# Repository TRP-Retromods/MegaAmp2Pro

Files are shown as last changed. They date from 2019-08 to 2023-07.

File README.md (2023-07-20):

# Mega Amp 2.0 Pro
Original design by Ace and Villahed94

What makes the Mega Amp 2.0 different from the original design?
Due to limitations of the chosen op-amps on the original Mega Amp, volume levels are limited to those of every Genesis made from the VA0 Genesis Model 2 onwards. With new components chosen for the Mega Amp 2.0, you can now blow your ears out with sound even louder than the loudest Genesis Model 1s.
Every Genesis will now be able to drive headphones, as well. The transistor buffers from the original design are gone, replaced by a TDA1308, a dual op-amp with a built-in headphone driver. It is this chip that is able to bring the higher volume and also simplify the design by integrating a superior headphone driver.
The Mega Amp 2.0 retains the 3.68KHz low-pass filtering for Genesis Model 1-like audio on the filtered setup, but the unfiltered setup now goes beyond the audible spectrum, filtering frequencies past 24.56KHz for the clearest sound possible.

This is the big one, the full-featured Mega Amp 2.0. It has it all: multiple different filter setups, Stereo and Mono audio, AND the added bonus of Sega CD audio mixing (Sega CD Model 2 or modded Sega CD Model 1 required to take advantage of this). Anyone who owns a Sega CD can choose what kind of audio they want out of their Genesis and Sega CD.

To sum up the Mega Amp 2.0:
-An even simpler design over the original Mega Amp (excluding the Mega Amp 2.0 Pro)
-Filtered circuits deliver the same sound as a VA0 to VA2 Genesis Model 1 minus distortion
-Unfiltered circuits deliver the full spectrum of the Genesis' audio output
-The loudest audio levels of any audio amp for the Genesis, including Sega’s amp for the VA3 Genesis Model 1
-Improved headphone support
-Sega CD pass-through for the Mega Amp 2.0 Pro for a true replacement audio circuit with no loss in functionality
-Mega Amp 2.0 Pro can add Sega CD pass-through to the Genesis Model 1

Sega-16 forums are downs, so I compile all explanation and installation in this doc: https://github.com/TRP-Retromods/MegaAmp2Pro/blob/master/MEGAAMP_2_DOC+INSTALL_V1.pdf

Quick Guide to help soldering the components on the PCB: https://github.com/TRP-Retromods/MegaAmp2Pro/blob/master/MEGAMP_2_PRO_QUICK_GUIDE_V3.pdf

Boards can be ordered on OSHPark https://oshpark.com/shared_projects/v1SMwG5q

https://youtu.be/V17gc4aD0Z8

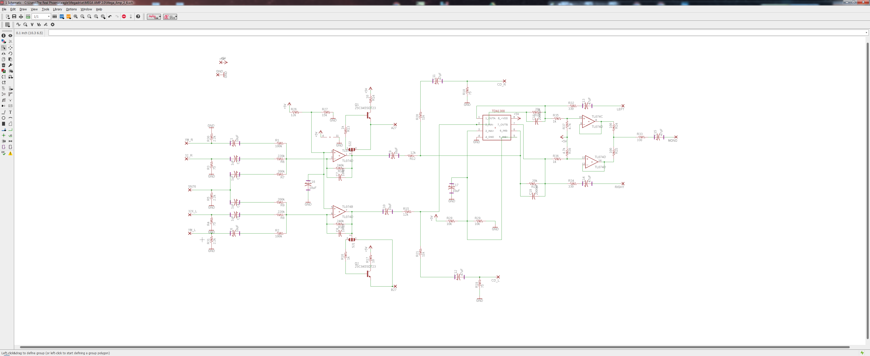
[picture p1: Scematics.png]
schematic


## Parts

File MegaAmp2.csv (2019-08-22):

Manufacturer Part Number | Manufacturer | Digi-Key Part Number | Customer Reference | Reference Designator | Packaging | Part Status | Quantity | Unit Price | Extended Price | Quantity Available | Mfg Std Lead Time | Description | RoHS Status | Lead Free Status | REACH Status | US Tariff Status
865080340001 | Wurth Electronics Inc. | 732-8411-1-ND | Sega Mega Amp 2.0 PRO | C1, C6, C9, C10, C16, C17 | Cut Tape (CT) | Active | 6 | 0.25000 | $1.50 | 3639 | 24 Weeks | CAP 10 UF 20% 16 V | RoHS Compliant | Lead free | REACH Unaffected | Tariff Eligible
865080640001 | Wurth Electronics Inc. | 732-8446-1-ND | Sega Mega Amp 2.0 PRO | C2, C3, C4, C5 | Cut Tape (CT) | Active | 4 | 0.26000 | $1.04 | 1479 | 24 Weeks | CAP 1 UF 20% 50 V | RoHS Compliant | Lead free | REACH Unaffected | Tariff Eligible
865080342006 | Wurth Electronics Inc. | 732-8416-1-ND | Sega Mega Amp 2.0 PRO | C11, C12, C13, C14, C15 | Cut Tape (CT) | Active | 5 | 0.28000 | $1.40 | 3305 | 24 Weeks | CAP 47 UF 20% 16 V | RoHS Compliant | Lead free | REACH Unaffected | Tariff Eligible
CL10C181JB8NNNC | Samsung Electro-Mechanics | 1276-1255-1-ND | Sega Mega Amp 2.0 PRO | C7, C8 (Mix Filtered) | Cut Tape (CT) | Active | 2 | 0.15000 | $0.30 | 439175 | Not Available | CAP CER 180PF 50V C0G/NP0 0603 | RoHS Compliant | Lead free | REACH Unaffected
CL10B202KB8NNNC | Samsung Electro-Mechanics | 1276-1983-1-ND | Sega Mega Amp 2.0 PRO | C18, C20 (Full Filtered) | Cut Tape (CT) | Active | 2 | 0.15000 | $0.30 | 260929 | Not Available | CAP CER 2000PF 50V X7R 0603 | RoHS Compliant | Lead free | REACH Unaffected | Tariff Eligible
TMBT3904,LM | Toshiba Semiconductor and Storage | TMBT3904LMCT-ND | Sega Mega Amp 2.0 PRO | Q1, Q2 | Cut Tape (CT) | Active | 2 | 0.28000 | $0.56 | 1255 | 12 Weeks | TRANS NPN 50V 0.15A SOT23-3 | RoHS Compliant | Lead free | Not Available
TL074CD | Texas Instruments | 296-1283-5-ND | Sega Mega Amp 2.0 PRO | TL074 | Tube | Active | 1 | 0.91000 | $0.91 | 2910 | 6 Weeks | IC INST AMP 4 CIRCUIT 14SOIC | RoHS Compliant | Lead free | REACH Unaffected
RMCF0603FT10R0 | Stackpole Electronics Inc | RMCF0603FT10R0CT-ND | Sega Mega Amp 2.0 PRO | R14, R17 | Cut Tape (CT) | Active | 2 | 0.15000 | $0.30 | 419828 | 17 Weeks | RES 10 OHM 1% 1/10W 0603 | RoHS Compliant | Lead free | REACH Unaffected | Tariff Eligible
RC0603FR-07100RL | Yageo | 311-100HRCT-ND | Sega Mega Amp 2.0 PRO | R24, R25 | Cut Tape (CT) | Active | 2 | 0.15000 | $0.30 | 26290992 | 16 Weeks | RES SMD 100 OHM 1% 1/10W 0603 | RoHS Compliant | Lead free | REACH Unaffected | Tariff Eligible
RMCF0603FT75R0 | Stackpole Electronics Inc | RMCF0603FT75R0CT-ND | Sega Mega Amp 2.0 PRO | R3, R4, R18, R19 | Cut Tape (CT) | Active | 4 | 0.15000 | $0.60 | 150899 | 17 Weeks | RES 75 OHM 1% 1/10W 0603 | RoHS Compliant | Lead free | REACH Unaffected | Tariff Eligible
CRGH0603F2K2 | TE Connectivity Passive Product | A129540CT-ND | Sega Mega Amp 2.0 PRO | R5, R30, R31 | Cut Tape (CT) | Active | 3 | 0.15000 | $0.45 | 16703 | 28 Weeks | CRGH0603 1% 2K2 0.2W | RoHS Compliant | Lead free | Not Available
RMCF0603FT11K0 | Stackpole Electronics Inc | RMCF0603FT11K0CT-ND | Sega Mega Amp 2.0 PRO | R20, R21 | Cut Tape (CT) | Active | 2 | 0.15000 | $0.30 | 140617 | 17 Weeks | RES 11K OHM 1% 1/10W 0603 | RoHS Compliant | Lead free | REACH Unaffected | Tariff Eligible
RMCF0603FT12K0 | Stackpole Electronics Inc | RMCF0603FT12K0CT-ND | Sega Mega Amp 2.0 PRO | R12, R15, R26 | Cut Tape (CT) | Active | 3 | 0.15000 | $0.45 | 333582 | 17 Weeks | RES 12K OHM 1% 1/10W 0603 | RoHS Compliant | Lead free | REACH Unaffected | Tariff Eligible
RMCF0603FG1K00 | Stackpole Electronics Inc | RMCF0603FG1K00CT-ND | Sega Mega Amp 2.0 PRO | R13, R16, R35, R36 | Cut Tape (CT) | Active | 2 | 0.15000 | $0.30 | 182303 | 17 Weeks | RES 1K OHM 1% 1/10W 0603 | RoHS Compliant | Lead free | REACH Unaffected | Tariff Eligible
RMCF0603FT16K0 | Stackpole Electronics Inc | RMCF0603FT16K0CT-ND | Sega Mega Amp 2.0 PRO | R27 | Cut Tape (CT) | Active | 1 | 0.15000 | $0.15 | 43103 | 17 Weeks | RES 16K OHM 1% 1/10W 0603 | RoHS Compliant | Lead free | REACH Unaffected | Tariff Eligible
RMCF0603FT15K0 | Stackpole Electronics Inc | RMCF0603FT15K0CT-ND | Sega Mega Amp 2.0 PRO | R27 | Cut Tape (CT) | Active | 1 | 0.15000 | $0.15 | 245293 | 17 Weeks | RES 15K OHM 1% 1/10W 0603 | RoHS Compliant | Lead free | REACH Unaffected | Tariff Eligible
RC0603FR-0720KL | Yageo | 311-20.0KHRCT-ND | Sega Mega Amp 2.0 PRO | R22, R23 | Cut Tape (CT) | Active | 2 | 0.15000 | $0.30 | 8330634 | 16 Weeks | RES SMD 20K OHM 1% 1/10W 0603 | RoHS Compliant | Lead free | REACH Unaffected | Tariff Eligible
RMCF0603FT200K | Stackpole Electronics Inc | RMCF0603FT200KCT-ND | Sega Mega Amp 2.0 PRO | R7, R9 | Cut Tape (CT) | Active | 2 | 0.15000 | $0.30 | 1424 | 17 Weeks | RES 200K OHM 1% 1/10W 0603 | RoHS Compliant | Lead free | REACH Unaffected
RMCF0603FG100K | Stackpole Electronics Inc | RMCF0603FG100KCT-ND | Sega Mega Amp 2.0 PRO | R1, R2 | Cut Tape (CT) | Active | 2 | 0.15000 | $0.30 | 305802 | 17 Weeks | RES 100K OHM 1% 1/10W 0603 | RoHS Compliant | Lead free | REACH Unaffected | Tariff Eligible
RMCF0603FT240K | Stackpole Electronics Inc | RMCF0603FT240KCT-ND | Sega Mega Amp 2.0 PRO | R11, R10 | Cut Tape (CT) | Active | 2 | 0.15000 | $0.30 | 4599 | 17 Weeks | RES 240K OHM 1% 1/10W 0603 | RoHS Compliant | Lead free | REACH Unaffected
C0603C270J5GACTU | KEMET | 399-1054-1-ND | Sega Mega Amp 2.0 PRO | C7, C8 (Unfiltered) | Cut Tape (CT) | Active | 2 | 0.15000 | $0.30 | 316020 | 33 Weeks | CAP CER 27PF 50V C0G/NP0 0603 | RoHS Compliant | Lead free | REACH Unaffected
CR0603-FX-1002ELF | Bourns Inc. | CR0603-FX-1002ELFCT-ND | Sega Mega Amp 2.0 PRO | R28, R29 | Cut Tape (CT) | Active | 2 | 0.15000 | $0.30 | 239308 | 14 Weeks | RES SMD 10K OHM 1% 1/10W 0603 | RoHS Compliant | Lead free | REACH Unaffected
KTR03EZPF2203 | Rohm Semiconductor | RHM220KAYCT-ND | Sega Mega Amp 2.0 PRO | R6, R8 | Cut Tape (CT) | Active | 2 | 0.23000 | $0.46 | 1571 | 10 Weeks | RES SMD 220K OHM 1% 1/10W 0603 | RoHS Compliant | Lead free | REACH Unaffected
RMCF0603FT330R | Stackpole Electronics Inc | RMCF0603FT330RCT-ND | Sega Mega Amp 2.0 PRO | R32, R33, R34 | Cut Tape (CT) | Active | 3 | 0.15000 | $0.45 | 379642 | 17 Weeks | RES 330 OHM 1% 1/10W 0603 | RoHS Compliant | Lead free | REACH Unaffected
SA5532ADR | Texas Instruments | 296-16994-1-ND | Sega Mega Amp 2.0 PRO | TDA1308 replacement | Cut Tape (CT) | Active | 1 | 1.31000 | $1.31 | 15908 | 6 Weeks | IC INST AMP 2 CIRCUIT 8SOIC | RoHS Compliant | Lead free | REACH Unaffected
RMCF0603FT4K70 | Stackpole Electronics Inc | RMCF0603FT4K70CT-ND | Sega Mega Amp 2.0 PRO | R37, R38 | Cut Tape (CT) | Active | 2 | 0.15000 | $0.30 | 718263 | 17 Weeks | RES 4.7K OHM 1% 1/10W 0603 | RoHS Compliant | Lead free | REACH Unaffected | Tariff Eligible

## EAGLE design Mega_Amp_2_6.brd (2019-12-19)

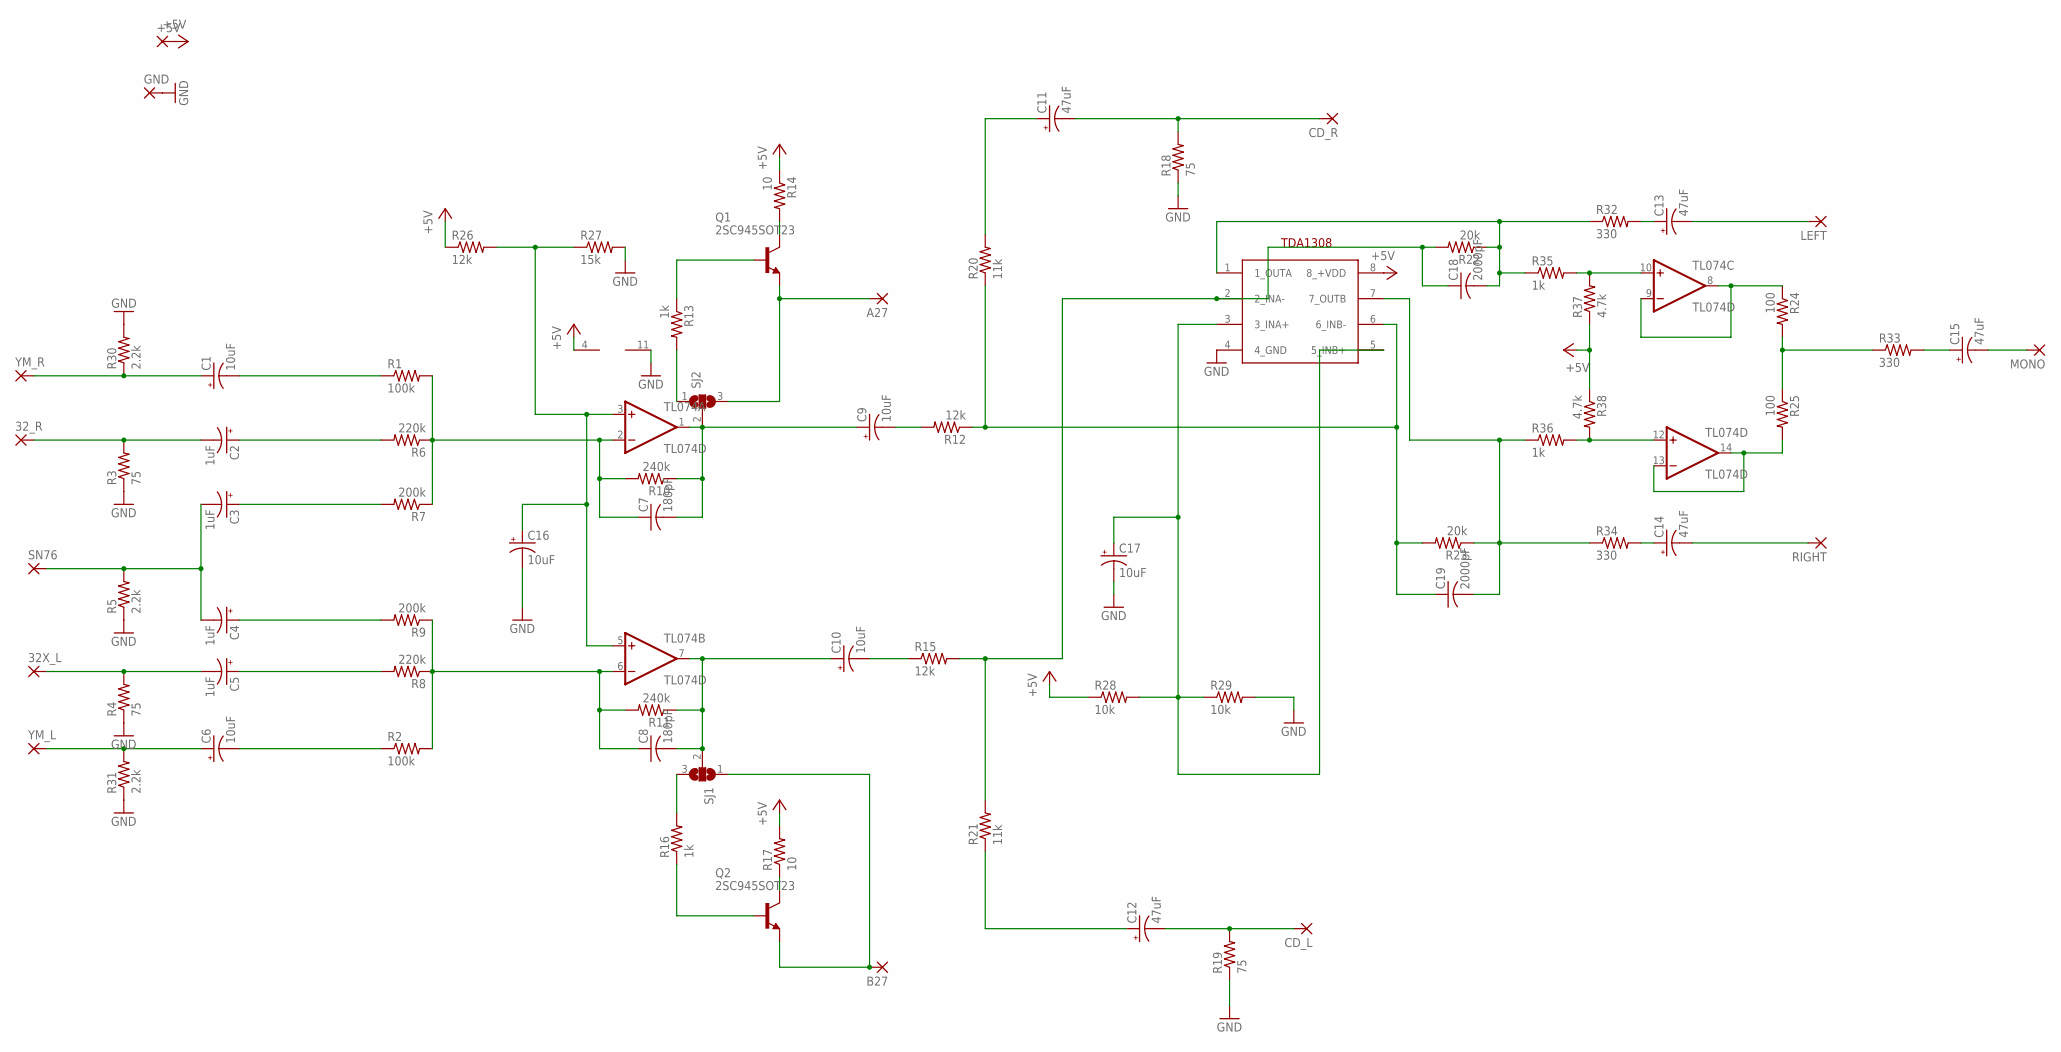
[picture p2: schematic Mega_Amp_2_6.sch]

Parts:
32X_L, 32_R: SMD2; SMD1,27-2,54
+5V: SMD5; SMD2,54-5,08
A27: SMD2; SMD1,27-2,54
B27: SMD2; SMD1,27-2,54
C1, C6, C9, C10, C16, C17: 10uF; 153CLV-0405
C2, C3, C4, C5: 1uF; 153CLV-0405
C7, C8: 180pF; C0603
C11, C12, C13, C14, C15: 47uF; 153CLV-0505
C18, C19: 2000pF; C0603
CD_L: SMD2; SMD1,27-2,54
CD_R: SMD2; SMD1,27-2,54
GND: SMD5; SMD2,54-5,08
LEFT: SMD2; SMD1,27-2,54
MONO: SMD2; SMD1,27-2,54
Q1, Q2: 2SC945SOT23; SOT23
R1, R2: 100k; R0603
R3, R4, R18, R19: 75; R0603
R5, R30, R31: 2.2k; R0603
R6, R8: 220k; R0603
R7, R9: 200k; R0603
R10, R11: 240k; R0603
R12, R15, R26: 12k; R0603
R13, R16, R35, R36: 1k; R0603
R14, R17: 10; R0603
R20, R21: 11k; R0603
R22, R23: 20k; R0603
R24, R25: 100; R0603
R27: 15k; R0603
R28, R29: 10k; R0603
R32, R33, R34: 330; R0603
R37, R38: 4.7k; R0603
RIGHT: SMD2; SMD1,27-2,54
SJ1, SJ2: SJ2W; SJ_2
SN76: SMD2; SMD1,27-2,54
TDA1308: TDA1308SO8; SO8
TL074: TL074D; SO14
YM_L: SMD2; SMD1,27-2,54
YM_R: SMD2; SMD1,27-2,54

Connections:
+5V: +5V.1, R14.1, R17.2, R26.1, R28.1, R37.1, R38.1, TDA1308.8 (8_+VDD), TL074.4 (V+)
GND: C16.-, C17.-, GND.1, R3.1, R4.1, R5.1, R18.1, R19.1, R27.2, R29.2, R30.2, R31.1, TDA1308.4 (4_GND), TL074.11 (V-)
unnamed: C1.+, R30.1, YM_R.1
unnamed: C1.-, R1.1
unnamed: 32_R.1, C2.-, R3.2
unnamed: C2.+, R6.2
unnamed: C3.-, C4.-, R5.2, SN76.1
unnamed: C3.+, R7.2
unnamed: C4.+, R9.2
unnamed: C7.1, R1.2, R6.1, R7.1, R10.2, TL074.2 (-IN)
unnamed: C8.1, R2.2, R8.1, R9.1, R11.2, TL074.6 (-IN)
unnamed: C5.+, R8.2
unnamed: C6.-, R2.1
unnamed: 32X_L.1, C5.-, R4.2
unnamed: C6.+, R31.2, YM_L.1
unnamed: C16.+, R26.2, R27.1, TL074.3 (+IN), TL074.5 (+IN)
unnamed: C7.2, C9.+, R10.1, SJ2.2, TL074.1 (OUT)
unnamed: Q1.1 (B), R13.1
unnamed: C8.2, C10.+, R11.1, SJ1.2, TL074.7 (OUT)
unnamed: Q1.3 (C), R14.2
unnamed: A27.1, Q1.2 (E), SJ2.3
unnamed: C9.-, R12.2
unnamed: C19.1, R12.1, R20.1, R23.2, TDA1308.6 (6_INB-)
unnamed: C11.+, R20.2
unnamed: C11.-, CD_R.1, R18.2
unnamed: C13.-, LEFT.1
unnamed: C15.-, MONO.1
unnamed: R24.2, R25.1, R33.1
unnamed: C10.-, R15.1
unnamed: C17.+, R28.2, R29.1, TDA1308.3 (3_INA+), TDA1308.5 (5_INB+)
unnamed: Q2.1 (B), R16.1
unnamed: Q2.3 (C), R17.1
unnamed: B27.1, Q2.2 (E), SJ1.1
unnamed: C12.+, R21.1
unnamed: C12.-, CD_L.1, R19.2
unnamed: C18.1, R15.2, R21.2, R22.2, TDA1308.2 (2_INA-)
unnamed: R24.1, TL074.8 (OUT), TL074.9 (-IN)
unnamed: R25.2, TL074.13 (-IN), TL074.14 (OUT)
unnamed: C14.-, RIGHT.1
unnamed: C13.+, R32.2
unnamed: C14.+, R34.2
unnamed: C15.+, R33.2
unnamed: R13.2, SJ2.1
unnamed: C19.2, R23.1, R34.1, R36.1, TDA1308.7 (7_OUTB)
unnamed: R16.2, SJ1.3
unnamed: R35.2, R37.2, TL074.10 (+IN)
unnamed: C18.2, R22.1, R32.1, R35.1, TDA1308.1 (1_OUTA)
unnamed: R36.2, R38.2, TL074.12 (+IN)

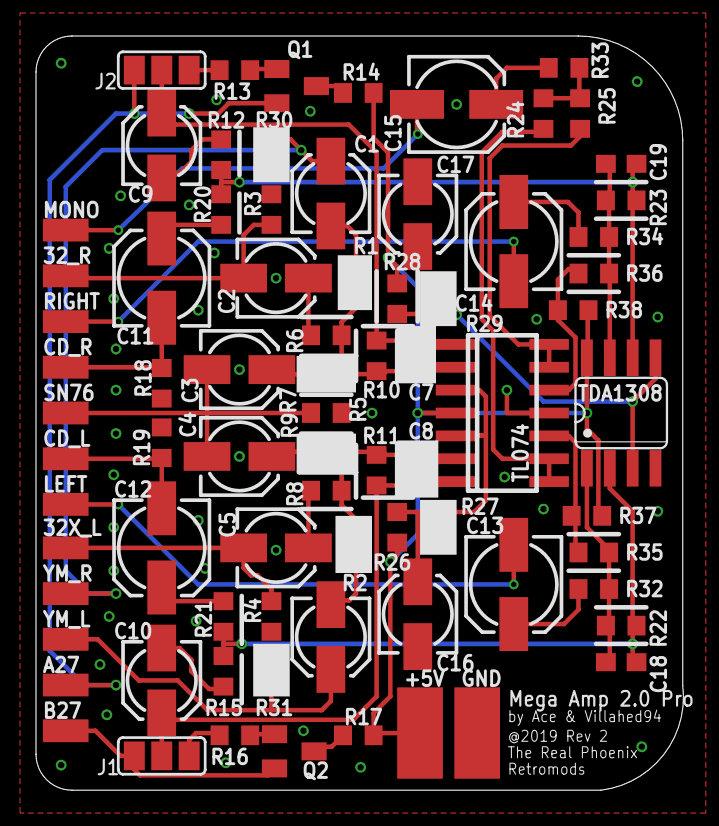
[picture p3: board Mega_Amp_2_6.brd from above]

Board: 2 copper layers, 36.0 x 41.9 mm, 77 parts (0 on the bottom side), 48 nets.

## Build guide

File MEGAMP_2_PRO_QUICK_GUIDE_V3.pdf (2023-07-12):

# MEGA AMP 2.0 PRO

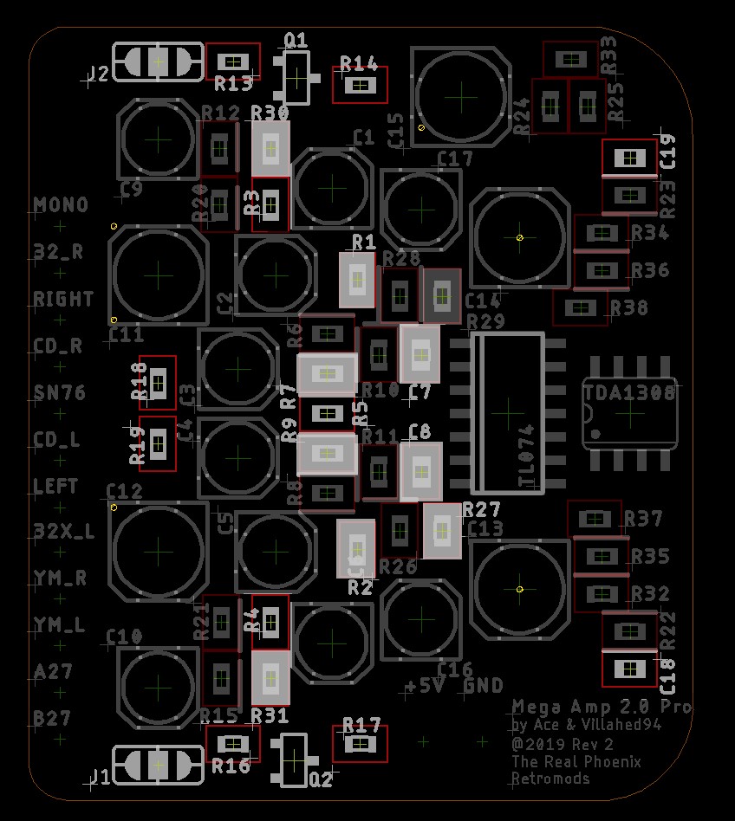
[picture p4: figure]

| YM2612 VA2/VA2.3 | ASIC/DISCRETE YM3438 VA0/VA1/VA1.8/VA3 | GOAC YM3438 VA4 | Notes :
R1/R2 | 10k Ohm | 100k Ohm | 75k Ohm
R7/R9 | 200k Ohm | 200k Ohm | 130k Ohm
R30/R31 | 2.2k Ohm* | - | - | *R30/R31 optional for retrofit a YM2612 on a ASIC YM3438
R27 | 16k Ohm | 15k Ohm | 15k Ohm

R3/R4 = 75 Ohm - 32X input, only needed if not on motherboard
R18/R19 = 75 Ohm – CD input, only needed if not on motherboard R5 = 2.2k Ohm - only needed if not on motherboard

Jumper Settings
For model 2 VA0/VA1/V1.8: | Other models:

Filtering Caps
| Unfiltered | Mix Filtered | Full Filtered
C7/C8 | 27pF | 180pF | 27pF
C18/C19 | - | - | 2000pF

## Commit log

2019-05-25 Add Rev2 Eagle Files
    [Mega_Amp_2_6.brd, Mega_Amp_2_6.sch]
2019-05-25 Add Gerber files
2019-05-25 Add BOM from Digikey
    [MegaAmp2.csv]
2019-05-25 update BOM for REV2
    [MegaAmp2.csv]
